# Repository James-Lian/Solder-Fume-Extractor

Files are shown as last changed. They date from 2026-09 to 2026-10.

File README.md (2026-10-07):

# 💨 Solder-Fume-Extractor
A small solder fume extractor complete with an air quality sensor for hobbyist soldering applications. Soldering can get pretty fume-y (pun intended), irritating the eyes, nose, and throat. While this extractor won't be as good as a commercial-grade fume hood, the filter will at least mitigate some of solder smoke. 
<br>
<br>
Encompasses a control board with the air quality sensor, a 12V PC fan, activated carbon filter, and custom-designed 3d-printed casing to house everything. 
<br>
<br>
Stardance Project Tracker (Devlogs): [https://stardance.hackclub.com/projects/36238](https://stardance.hackclub.com/projects/36238)



## 💡 Features
- powered by a [12V DC power supply](https://www.amazon.ca/dp/B09W8S3FBV)
- 0.91inch OLED SSD1306
- LM2596-3.3 buck converter for 3V3 supply
- ENS160+AHT21 sensor to detect VOCs and eCO2
- ESP-01S microcontroller
- custom 3d-printed casing
- [12V desk fan](https://www.amazon.ca/dp/B0DPWWMNYM) which pulls solder fumes through an [activated carbon filter](https://www.amazon.ca/dp/B0DVX29MLH?ref=ppx_yo2ov_dt_b_fed_asin_title)
- flip flop switch circuit + MOSFET to control the fan, flyback diode to prevent MOSFET damage

## 📄 PCB & Schematic


<br>
<br>
Note: additional space is intentionally left empty at the bottom left of the PCB to leave space for the sensor components.

## 🧱 CAD Model
The casing for both the controller board and desk fan were designed in Fusion360. The casing for the controller board covers all the components apart from the air quality sensor, which, of course, needs ample exposure to the air to make an accurate reading. 

## ⚙️ Assembly
1. Download the production files from the production folder and upload them to a manufacturer like JLCPCB
2. Upload the code to the ESP-01S through something like the [CP2102 module](https://www.amazon.ca/dp/B07D6LLX19)
3. After acquiring the PCB, solder all the components to the board. Ensure you leave enough spacing between the PCB and the [right-angle male headers](https://www.amazon.ca/dp/B01461DQ6S?ref=ppx_yo2ov_dt_b_fed_asin_title) for the fan's female connectors to fit.
4. The fan's casing is in three parts. Add heatset inserts to the thickest part, and then sandwich your activated carbon filter between the two grill frames before assembling all three together with 4 M3 screws.
5. The PCB's controller casing comes with an optional screw hole for secure placement. In my experience, it's not needed.  

## ⌨️ Code + Sensors
The code comes with preventative measures to prevent OLED screen burn in, such as by inverting or scrolling the text, and turning off the screen at times. Do note that the ENS160+AHT21 sensor needs to be (unfortunately) powered on for at least 24 hours (ideally 48) to output accurate readings. 

## 📋 BOM
Here's a list of components for the build (more complete version with links + prices in root repository):
### PCB
| Designator | Footprint | Quantity |
| --- | --- | --- |
| C1 680µF | CP_Radial_D10.0mm_P5.00mm | 1 |
| C2 220µF | CP_Radial_D6.3mm_P2.50mm | 1 |
| C3, C4 0.1µF | 0805 | 2 |
| C5 10nF | 0805 | 1 |
| C6 1µF | 0805 | 1 |
| D1 1N5822 | D_DO-201AD_P15.24mm_Horizontal | 1 |
| D2 1N4001 | D_DO-41_SOD81_P10.16mm_Horizontal | 1 |
| D3, D4 1N4148 | D_DO-35_SOD27_P7.62mm_Horizontal | 2 |
| J1 Barrel_Jack_Switch | XKB_DC-005-5A-2.0 | 1 |
| J2 [Fan](https://www.amazon.ca/dp/B0DPWWMNYM) | [PinHeader_1x03_P2.54mm_Horizontal](https://www.amazon.ca/dp/B01461DQ6S?ref=ppx_yo2ov_dt_b_fed_asin_title) | 1 |
| [Activated Carbon Filter](https://www.amazon.ca/dp/B0DVX29MLH?ref=ppx_yo2ov_dt_b_fed_asin_title) | | 1 |
| [12V DC Power Supply](https://www.amazon.ca/dp/B09W8S3FBV) | | 1 |
| L1 33µH | L_Bourns_SRU5016_5.2x5.2mm | 1 |
| Q1 STP55NF06L | TO-220-3_Vertical | 1 |
| Q2, Q3 PN2222 | TO-92_Inline | 2 |
| R1, R4, R5, R8 10kΩ | R_Axial_DIN0207_L6.3mm_D2.5mm_P7.62mm_Horizontal | 4 |
| R2, R3 1kΩ | R_Axial_DIN0207_L6.3mm_D2.5mm_P7.62mm_Horizontal | 2 |
| R6, R7 100kΩ | R_Axial_DIN0207_L6.3mm_D2.5mm_P7.62mm_Horizontal | 2 |
| SW1 CherryMXSwitch | SW_Cherry_MX_1.00u_PCB | 1 |
| U1 LM2596S-3.3 | TO-263-5_TabPin3 | 1 |
| U2 ESP-01S | PinSocket_2x04_P2.54mm_Vertical | 1 |
| U3 ENS160+AHT21 | PinSocket_1x08_P2.54mm_Vertical | 1 |
| U4 0.91inch SSD1306 OLED | ER_OLEDM0.91_1x-I2C | 1 |

## 🖼️ Final Build Pictures




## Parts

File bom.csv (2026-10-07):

Designator | Footprint | Quantity | Value | Link | Price (USD)
C1 | CP_Radial_D10.0mm_P5.00mm | 1 | 680µF | https://www.lcsc.com/product-detail/C23777.html?s_z=n_q_GR687M035G20RR0VL4FP0 | $0.48
C2 | CP_Radial_D6.3mm_P2.50mm | 1 | 220µF | https://www.lcsc.com/product-detail/C2036.html?s_z=n_q_C2036&globalKeyword=C2036 | $0.08
C3, C4 | 0805 | 2 | 0.1µF | https://www.lcsc.com/product-detail/C1711.html?s_z=n_q_C1711&globalKeyword=C1711 | $0.32
C5 | 0805 | 1 | 10nF | https://www.lcsc.com/product-detail/C1710.html?s_z=n_q_CL21B103KBANNNC | $0.0116
C6 | 0805 | 1 | 1µF | https://www.lcsc.com/product-detail/C2907219.html?s_z=n_q_p_1%2520%25C2%25B5F%25200805 | $0.34
D1 | D_DO-201AD_P15.24mm_Horizontal | 1 | 1N5822 | https://www.lcsc.com/product-detail/C2476.html?s_z=n_q_C2476&globalKeyword=C2476 | $0.35
D2 | D_DO-41_SOD81_P10.16mm_Horizontal | 1 | 1N4001 | https://www.lcsc.com/product-detail/C47018536.html?s_z=n_q_C47018536&globalKeyword=C47018536 | $0.08
D3, D4 | D_DO-35_SOD27_P7.62mm_Horizontal | 2 | 1N4148 | https://www.lcsc.com/product-detail/C85057.html?s_z=n_q_C85057&globalKeyword=C85057 | $0.11
J1 | XKB_DC-005-5A-2.0 | 1 | Barrel_Jack_Switch | https://www.lcsc.com/product-detail/C381116.html?s_z=n_q_C381116&globalKeyword=C381116 | $0.52
J2 | PinHeader_1x03_P2.54mm_Horizontal | 1 | Fan | https://www.amazon.ca/dp/B01461DQ6S?ref=ppx_yo2ov_dt_b_fed_asin_title | $2.19
12V Desk Fan | N/A | 1 | N/A | https://www.amazon.ca/dp/B0DPWWMNYM | $12.00
Activated Carbon Filter | N/A | 1 | N/A | https://amazon.ca/dp/B0DVX29MLH?ref=ppx_yo2ov_dt_b_fed_asin_title | $14.05
12V DC Power Supply | N/A | 1 | N/A | https://www.amazon.ca/dp/B09W8S3FBV?th=1 | $10.20
L1 | L_Bourns_SRU5016_5.2x5.2mm | 1 | 33µH | https://www.lcsc.com/product-detail/C5760316.html?s_z=n_q_C5760316&globalKeyword=C5760316 | $1.29
Q1 | TO-220-3_Vertical | 1 | STP55NF06L | https://www.lcsc.com/product-detail/C77582.html?s_z=n_q_C77582&globalKeyword=C77582 | $2.57
Q2, Q3 | TO-92_Inline | 2 | PN2222 | https://www.lcsc.com/product-detail/C50229644.html?s_z=n_q_2n2222%2520TO-92 | $0.05
R1, R4, R5, R8 | R_Axial_DIN0207_L6.3mm_D2.5mm_P7.62mm_Horizontal | 4 | 10kΩ | https://www.amazon.ca/dp/B07L851T3V?ref=ppx_yo2ov_dt_b_fed_asin_title&th=1 | $0.03
R2, R3 | R_Axial_DIN0207_L6.3mm_D2.5mm_P7.62mm_Horizontal | 2 | 1kΩ | https://www.amazon.ca/dp/B07L851T3V?ref=ppx_yo2ov_dt_b_fed_asin_title&th=1 | $0.01
R6, R7 | R_Axial_DIN0207_L6.3mm_D2.5mm_P7.62mm_Horizontal | 2 | 100kΩ | https://www.amazon.ca/dp/B07L851T3V?ref=ppx_yo2ov_dt_b_fed_asin_title&th=1 | $0.01
SW1 | SW_Cherry_MX_1.00u_PCB | 1 | SW_Push | https://www.amazon.ca/dp/B0GY8BWBYJ?ref=ppx_yo2ov_dt_b_fed_asin_title | $0.18
U1 | TO-263-5_TabPin3 | 1 | LM2596S-3.3 | https://www.lcsc.com/product-detail/C42421958.html?s_z=n_q_C42421958&globalKeyword=C42421958 | $1.21
U2 | PinSocket_2x04_P2.54mm_Vertical | 1 | ESP-01S | https://www.amazon.ca/dp/B00O34AGSU | $7.04
U3 | PinSocket_1x08_P2.54mm_Vertical | 1 | ENS160+AHT21 | https://www.amazon.ca/dp/B0DH4M3JYW | $12.66
U4 | ER_OLEDM0.91_1x-I2C | 1 | ER_OLEDM0.91_1x-I2C | https://www.amazon.ca/dp/B085NHJYBV?th=1 (3 units) | $3.75

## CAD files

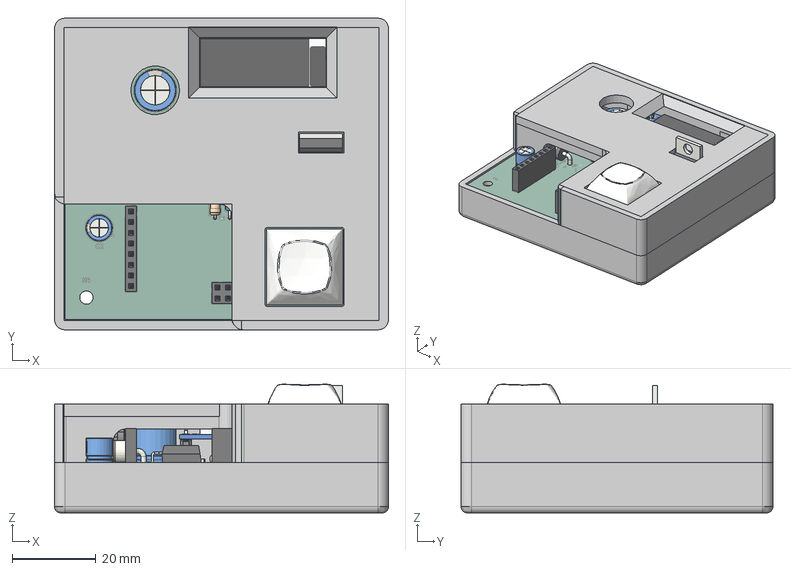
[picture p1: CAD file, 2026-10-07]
cad/DIY_Solder_Fume_PCB.step
79.6 x 74.3 x 30.7 mm
MX Mount v1

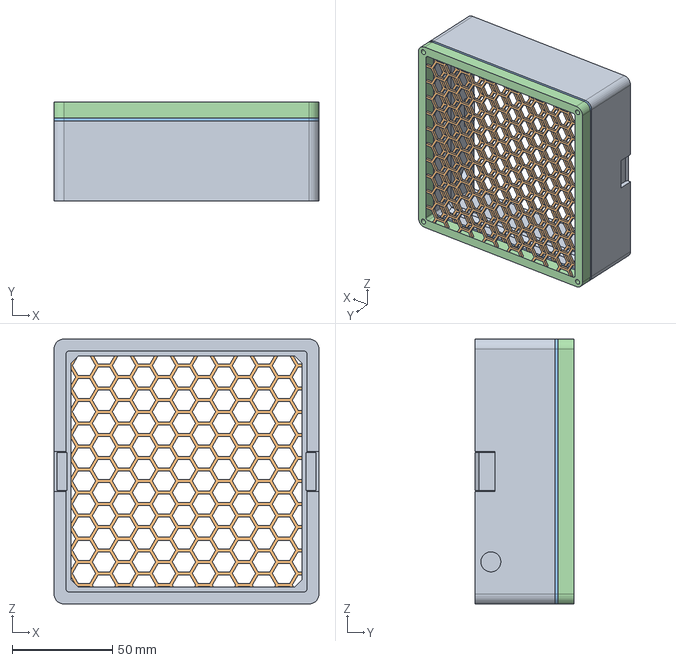
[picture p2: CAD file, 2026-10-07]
cad/DIY_Solder_Fume_Fan_Holder.step
132.0 x 49.5 x 132.0 mm

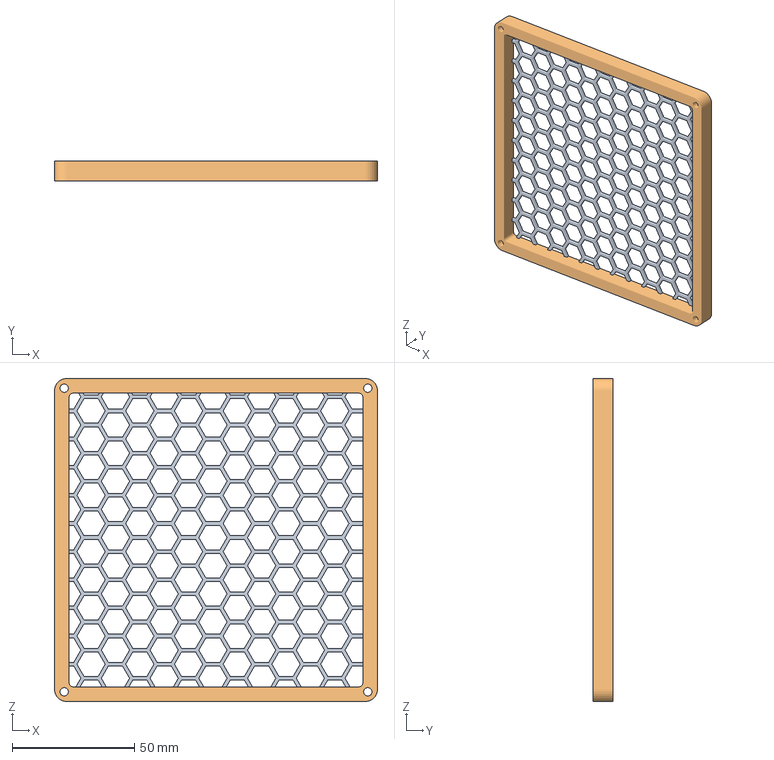
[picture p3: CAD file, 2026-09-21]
cad/FanGrill2.3mf
132.0 x 8.00 x 132.0 mm
Grill2
Grill2F

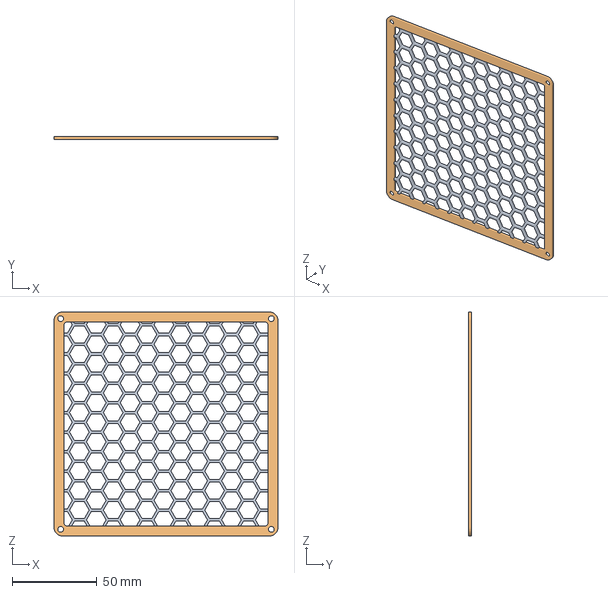
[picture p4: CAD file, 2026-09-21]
cad/FanGrill1.3mf
132.0 x 1.50 x 132.0 mm
Grill1
Grill1F

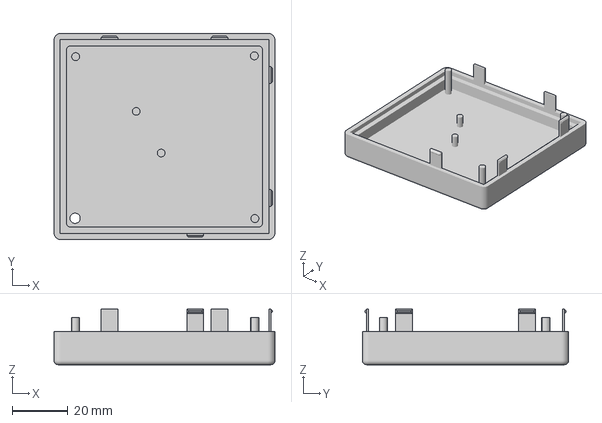
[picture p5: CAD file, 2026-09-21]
cad/Case_Bottom.3mf
79.6 x 74.3 x 20.0 mm

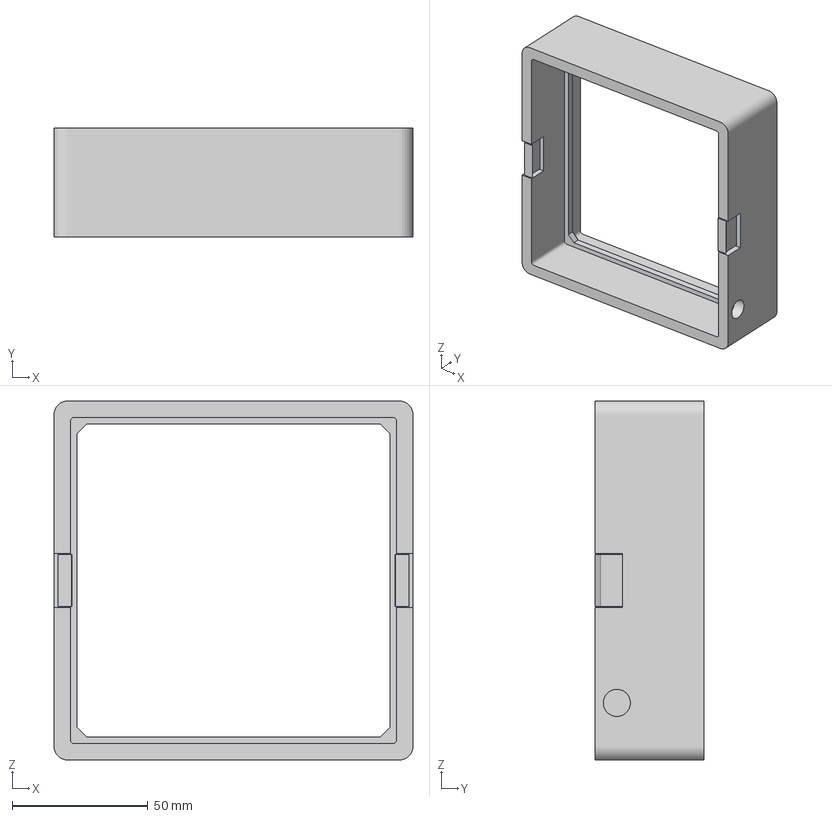
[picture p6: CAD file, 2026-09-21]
cad/FanBody.3mf
132.0 x 40.0 x 132.0 mm

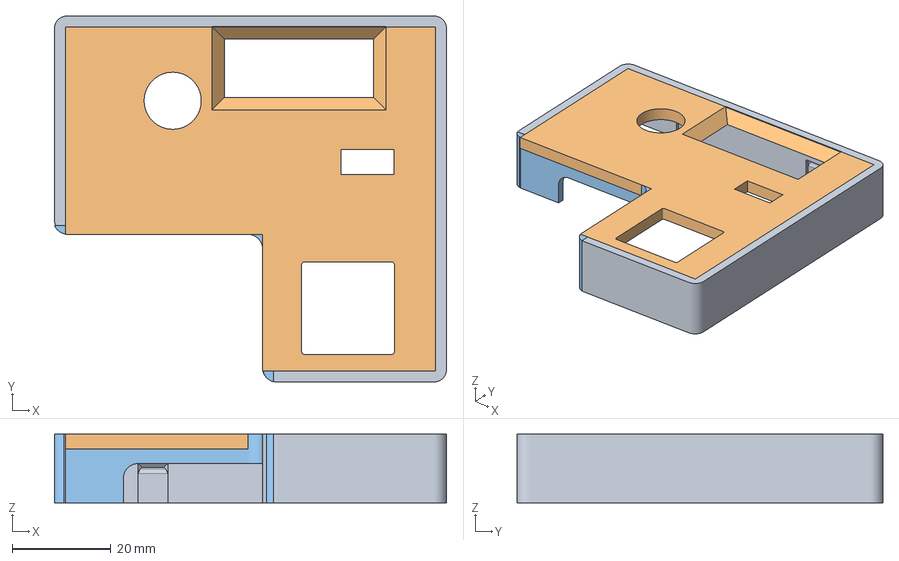
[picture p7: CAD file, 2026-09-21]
cad/Case_Top.3mf
79.6 x 74.3 x 14.0 mm

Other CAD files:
cad/DIY_Solder_Fume_Fan_Holder.f3d
cad/DIY_Solder_Fume_PCB.f3d

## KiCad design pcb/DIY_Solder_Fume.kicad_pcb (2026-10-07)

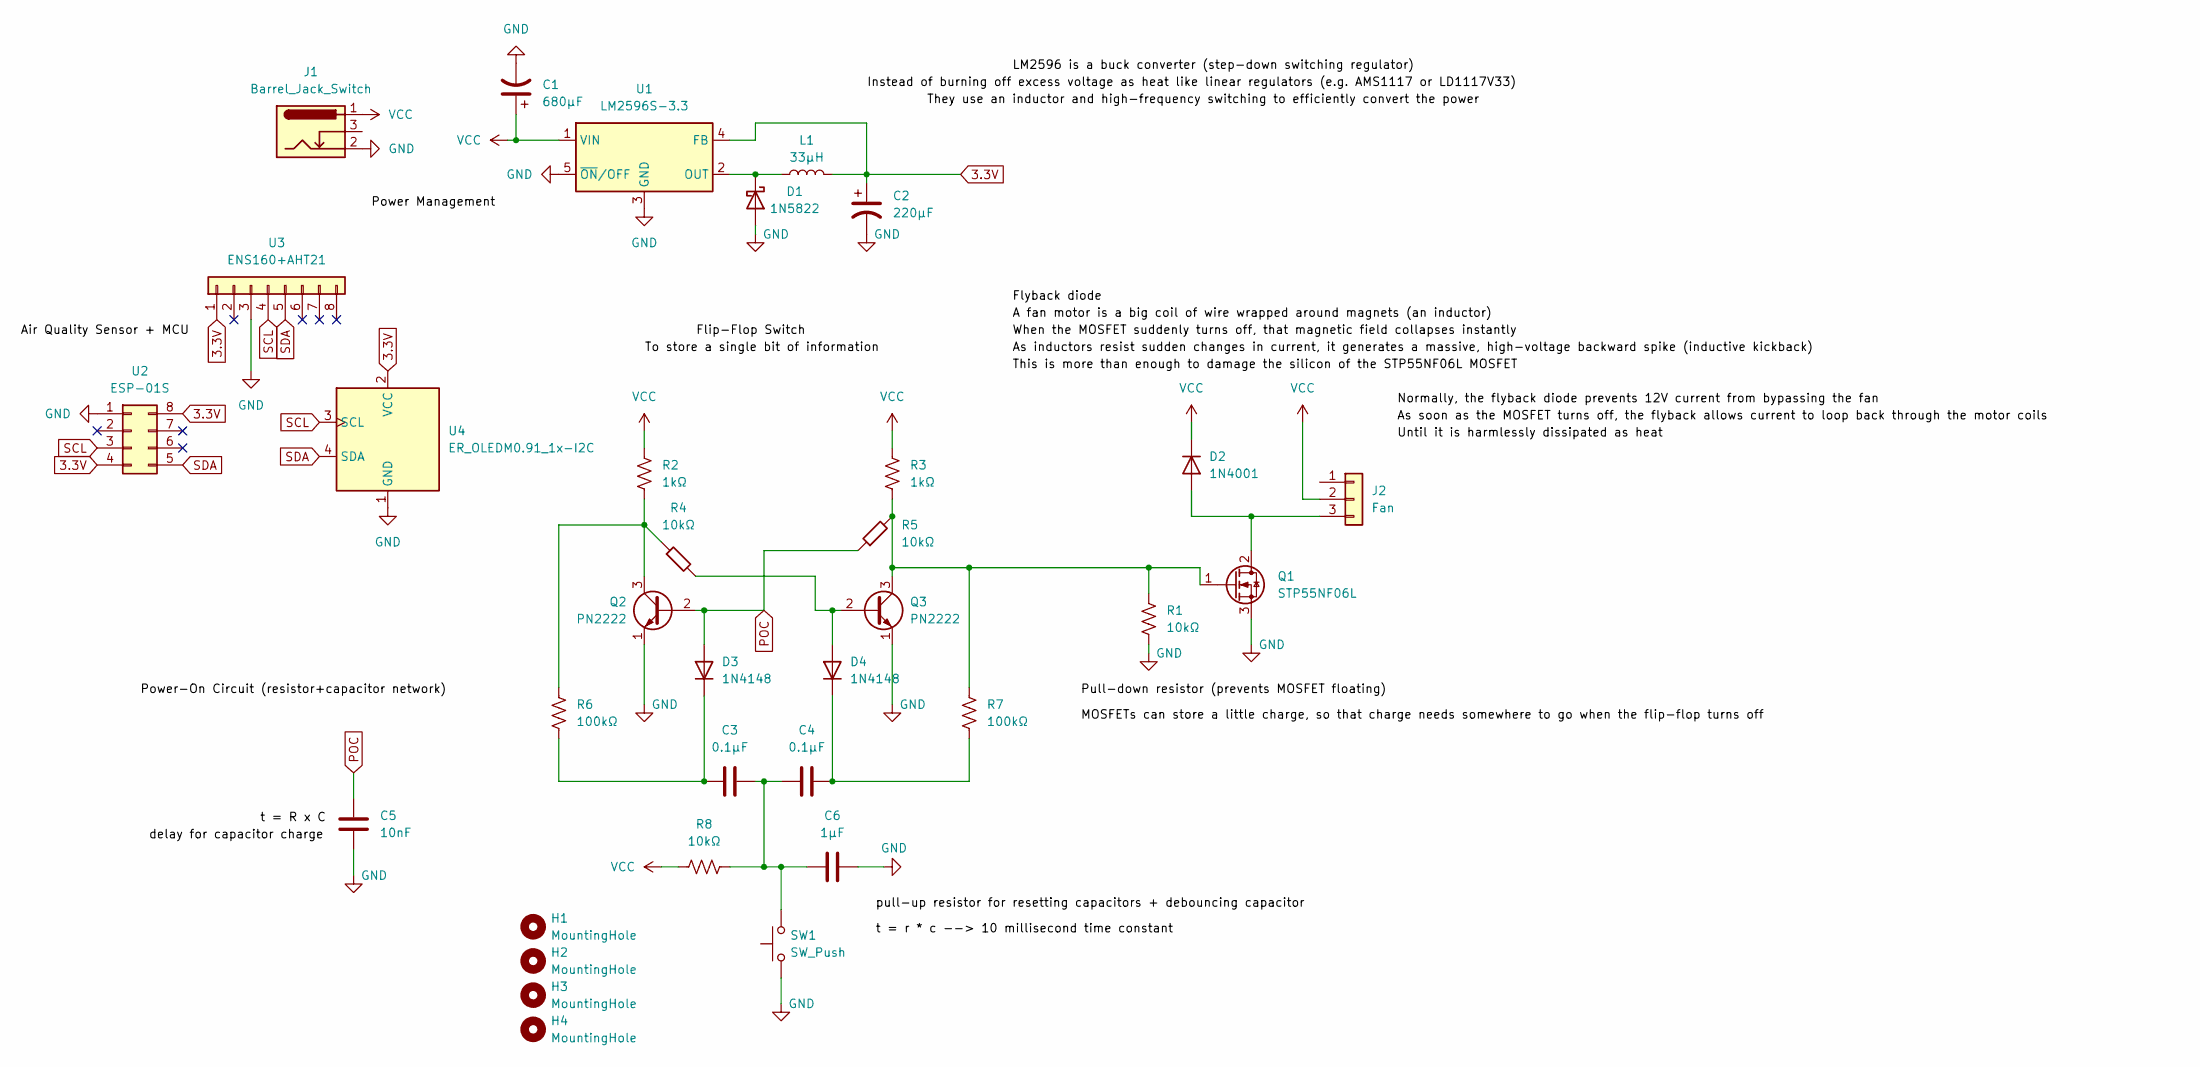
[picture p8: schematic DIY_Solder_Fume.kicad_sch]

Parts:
C1: 680µF; CP_Radial_D10.0mm_P5.00mm
C2: 220µF; CP_Radial_D6.3mm_P2.50mm
C3, C4: 0.1µF; C_0805_2012Metric
C5: 10nF; C_0805_2012Metric
C6: 1µF; C_0805_2012Metric
D1: 1N5822; D_DO-201AD_P15.24mm_Horizontal
D2: 1N4001; D_DO-41_SOD81_P10.16mm_Horizontal
D3, D4: 1N4148; D_DO-35_SOD27_P7.62mm_Horizontal
H1, H2, H3, H4: MountingHole; MountingHole_3.2mm_M3_Pad
J1: Barrel_Jack_Switch; XKB_DC-005-5A-2.0
J2: Fan; PinHeader_1x03_P2.54mm_Horizontal
L1: 33µH; L_Bourns_SRU5016_5.2x5.2mm
Q1: STP55NF06L; TO-220-3_Vertical
Q2, Q3: PN2222; TO-92_Inline
R1, R4, R5, R8: 10kΩ; R_Axial_DIN0207_L6.3mm_D2.5mm_P7.62mm_Horizontal
R2, R3: 1kΩ; R_Axial_DIN0207_L6.3mm_D2.5mm_P7.62mm_Horizontal
R6, R7: 100kΩ; R_Axial_DIN0207_L6.3mm_D2.5mm_P7.62mm_Horizontal
SW1: SW_Push; SW_Cherry_MX_1.00u_PCB
U1: LM2596S-3.3; TO-263-5_TabPin3
U2: ESP-01S; PinSocket_2x04_P2.54mm_Vertical
U3: ENS160+AHT21; PinSocket_1x08_P2.54mm_Vertical
U4: ER_OLEDM0.91_1x-I2C

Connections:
3.3V: C2.1, L1.2, U1.4 (FB), U2.4, U2.8, U3.1, U4.2 (VCC)
GND: C1.2, C2.2, C5.1, C6.1, D1.2 (A), J1.2, Q1.3 (S), Q2.1 (E), Q3.1 (E), R1.2, SW1.1, U1.3 (GND), U1.5 (~ON/OFF), U2.1, U3.3, U4.1 (GND)
unnamed: C3.2, C4.2, C6.2, R8.2, SW1.2
unnamed: D1.1 (K), L1.1, U1.2 (OUT)
unnamed: D2.2 (A), J2.3, Q1.2 (D)
unnamed: C3.1, D3.1 (K), R6.2
unnamed: D4.2 (A), Q3.2 (B), R4.2
unnamed: C4.1, D4.1 (K), R7.2
unnamed: Q1.1 (G), Q3.3 (C), R1.1, R3.2, R5.2, R7.1
unnamed: Q2.3 (C), R2.2, R4.1, R6.1
POC: C5.2, D3.2 (A), Q2.2 (B), R5.1
SCL: U2.3, U3.4, U4.3 (SCL)
SDA: U2.5, U3.5, U4.4 (SDA)
VCC: C1.1, D2.1 (K), J1.1, J2.2, R2.1, R3.1, R8.1, U1.1 (VIN)

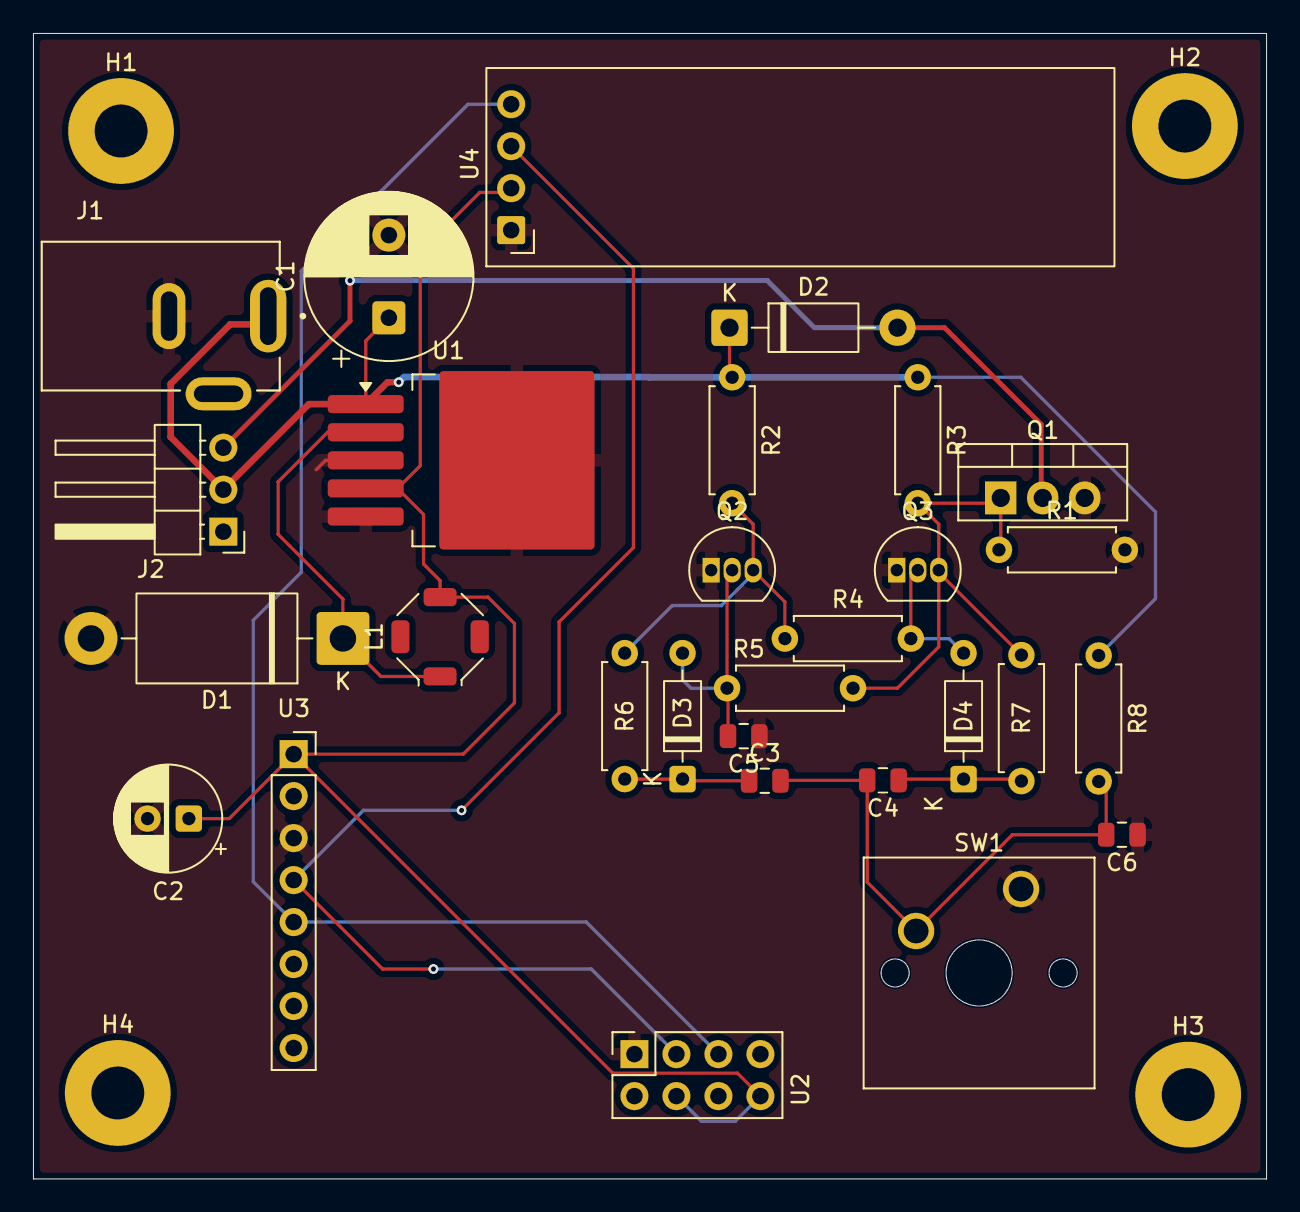
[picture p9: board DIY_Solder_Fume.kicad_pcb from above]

Board: 2 copper layers, 74.6 x 69.3 mm, 33 parts (0 on the bottom side), 14 nets.

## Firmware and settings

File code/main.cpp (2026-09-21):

#include <Arduino.h>
#include <Wire.h> // enables I2C communication
#include <Adafruit_GFX.h>
#include <Adafruit_SSD1306.h>
#include <Adafruit_AHTX0.h> // AHT21 library

#include "ScioSense_ENS160.h"  // ENS160 library

#define SCREEN_WIDTH 128 // OLED display width, in pixels
#define SCREEN_HEIGHT 32 // OLED display height, in pixels

#define SCREEN_ADDRESS 0x3C
Adafruit_SSD1306 display(SCREEN_WIDTH, SCREEN_HEIGHT, &Wire);

// AHT21 = temperature and humidity sensor
#define AHT21_ADDRESS 0x38
Adafruit_AHTX0 aht; 
#define separatorStr "--------------------------------------------------"
// AHT21 variables
float tempC; 
float tempF; 
float humidity;

// ENS160 = digital gas sensor
#define ENS160_ADDRESS 0x53
ScioSense_ENS160 ens160(ENS160_ADDRESS);
// ENS160 variables
int aqi = 0; // air quality index (1 to 5)
int tvoc = 0; // total VOCs (Volatile Organic Compounds) concentation in ppb (0 - 65000 ppb)
int eco2 = 0; // estimated CO2 equivalent (400 to 65000 ppm)

void setup() {
    Serial.begin(115200);
    while (!Serial);
    Serial.println("\nI2C Air Quality Sensor + OLED Display");

	Serial.println("Initializing I2C SSD1306 OLED...");
    // SDA = GPIO0, SCL = GPIO2
    Wire.begin(0, 2);
	Serial.println("SSD1306 initialized.");
	Serial.println(separatorStr);
	Serial.println();

	Serial.println("ENS160...");
	ens160.begin();
	delay(100);
	Serial.println(ens160.available() ? "ENS160 initialized." : "ENS160 initialization failed.");
	if (ens160.available()) {
		ens160.setMode(ENS160_OPMODE_STD); // begin() leaves the chip in IDLE; switch to Standard mode so it senses
	}
	Serial.println(separatorStr);

	if(!display.begin(SSD1306_SWITCHCAPVCC, SCREEN_ADDRESS)) {
		Serial.println(F("SSD1306 allocation failed"));
		for(;;); // Don't proceed, loop forever
	}

	bool okAht = aht.begin();
	if (!okAht) {
		Serial.println("AHT21 initialization failed.");
	}

	display.dim(true);
	display.setTextWrap(false); // clip at the panel edge instead of wrapping overflow onto a new line

	// clear buffer and show initial graphics
	display.clearDisplay();
	display.setTextSize(1);
	display.setTextColor(WHITE);
	display.setCursor(0, 0);
	display.println(F("Starting AQI sensor...")); // keeps strings in flash instead of dynamic RAM
	display.display();

	// scroll entire display to the right
	display.startscrollleft(0x00, 0x0F);
	delay(1500);
	display.stopscroll();
	display.setTextSize(1);
}

void loop() {
	uint32_t now = millis();
	static uint32_t lastSensor = 0;
	static uint32_t lastScroll = 0;
	static int scrollOffset = 0;

	// --- Sample sensors once per second ---
	if (now - lastSensor >= 1000) {
		lastSensor = now;

		sensors_event_t humidity1, temp;
		aht.getEvent(&humidity1, &temp);
		tempC = temp.temperature;
		tempF = temp.temperature * 9.0f / 5.0f + 32.0f;
		humidity = humidity1.relative_humidity;

		Serial.print("Temperature: ");
		Serial.print(tempC);
		Serial.print(" degrees C; ");
		Serial.print(tempF);
		Serial.println(" degrees F");

		Serial.print("Humidity: ");
		Serial.print(humidity);
		Serial.println("% rH");

		if (ens160.available()) {
			// Non-blocking: read whatever the ENS160 produced in its 1s cycle.
			// (measure(true) would block ~1s each call and stall the scroll.)
			ens160.set_envdata(tempC, humidity);
			ens160.measure(false);
			ens160.measureRaw(false);

			aqi  = ens160.getAQI();
			tvoc = ens160.getTVOC();
			eco2 = ens160.geteCO2();

			Serial.print("AQI: ");
			Serial.println(aqi);
			Serial.print("TVOC: ");
			Serial.print(tvoc);
			Serial.println("ppb");
			Serial.print("eCO2: ");
			Serial.print(eco2);
			Serial.println("ppm");
		}
	}

	// --- Build the two lines of text ---
	// NOTE: ESP8266 printf doesn't support %f, so format the floats first with dtostrf and stitch them into the line with integer %s
	char tmp1[8], tmp2[8], tmp3[8];
	dtostrf(tempC, 4, 1, tmp1);
	dtostrf(tempF, 6, 1, tmp2);
	dtostrf(humidity, 5, 1, tmp3);

	char line1[40];
	char line2[64];
	snprintf_P(line1, sizeof(line1), PSTR("%s C  %s F  %s %%rH"),
	           tmp1, tmp2, tmp3);
	if (ens160.available()) {
		snprintf_P(line2, sizeof(line2),
		           PSTR("AQI:%d | TVOC:%d ppb | eCO2:%d ppm"), aqi, tvoc, eco2);
	} else {
		snprintf_P(line2, sizeof(line2), PSTR("ENS160 not available"));
	}

	// Measure the wider line once and keep that scroll distance fixed so the
	// marquee doesn't jerk around when the digit widths change.
	static uint16_t scrollLimit = 0;
	if (scrollLimit == 0) {
		int16_t x1, y1, x2, y2;
		uint16_t w1 = 0, h1 = 0, w2 = 0, h2 = 0;
		display.getTextBounds(line1, 0, 0, &x1, &y1, &w1, &h1);
		display.getTextBounds(line2, 0, 0, &x2, &y2, &w2, &h2);
		// drawX starts at 128 (off the right edge) and must reach -maxW
		// (off the left edge), so the total travel is SCREEN_WIDTH + maxW,
		// plus a trailing gap for a blank pause before the loop restarts.
		const uint8_t scrollGap = 40;
		scrollLimit = SCREEN_WIDTH + (uint16_t)(w1 > w2 ? w1 : w2) + scrollGap;
	}

	//-----------------------------------------------------------------------------
	// Preventing OLED burn-in cycles
	// - phase 0: normal text
	// - phase 1: inverted text
	// - phase 2: all-black (fixed 7s)
	static uint32_t phaseStart = 0;
	static uint8_t phase = 0;

	// redraw further left every ~100 ms ---
	if (now - lastScroll >= 100) {
		lastScroll = now;
		if (phase == 2) {
			// Rest period
			display.invertDisplay(false);
			display.clearDisplay();
			display.display();
			// Phase 2 is 7s rest
			if (now - phaseStart >= 10000) {
				phase = 0;
				phaseStart = now;
			}
		} else {
			int16_t drawX = 128 - scrollOffset;

			display.clearDisplay();
			display.invertDisplay(phase == 1);
			display.setCursor(drawX, 4);
			display.print(line1);
			display.setCursor(drawX, 20);
			display.print(line2);
			display.display();

			// Advance one step toward the left edge.
			scrollOffset += 5;
			// When the text has finished a full pass across the panel,
			// move on to the next phase and restart the scroll.
			if (scrollOffset >= scrollLimit) {
				scrollOffset = 0;
				phase = (uint8_t)(phase + 1); // 0 -> 1 -> 2
				phaseStart = now;
			}
		}
	}
}

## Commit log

2026-09-16 Update from local repo
    [DIY_Solder_Fume.kicad_pcb, DIY_Solder_Fume.kicad_sch, bom.csv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]
2026-09-21 Enhance README with features and assembly details
    Expanded the README to include detailed features, assembly instructions, and final build pictures.
2026-09-21 Add I2C air quality sensor and OLED display code
2026-09-21 Add PlatformIO configuration for ESP01 1M board
2026-09-21 Update assembly instructions in README
    Added instructions for assembling the fan casing and PCB controller.
2026-09-29 Add root directory bom
    [bom.csv]
2026-09-29 Revise README for solder fume extractor clarity
    Updated the description to clarify the purpose and functionality of the solder fume extractor, emphasizing its benefits for hobbyist soldering applications.
2026-09-29 Add BOM section to README
    Added a Bill of Materials (BOM) section with component details.
2026-10-07 Modify bom.csv to add pricing and links
    Updated bill of materials to include links and prices for components.
    [bom.csv]
2026-10-07 Fix CSV formatting by adding a trailing comma
    [bom.csv]
2026-10-07 Update bom.csv with additional fields and entries
    [bom.csv]
2026-10-07 Fix BOM CSV formatting issues
    [bom.csv]
2026-10-07 Update bom.csv with new components and remove duplicates
    Removed duplicate entries and added new components with links and prices.
    [bom.csv]
2026-10-07 Update bom.csv
    Updated the URL for the Activated Carbon Filter to a more direct link.
    [bom.csv]
2026-10-07 Modify bom.csv for price column and formatting
    Updated the price column to 'Price per unit (USD)' and adjusted price formatting.
    [bom.csv]
2026-10-07 Revise BOM with pricing and links for components
    Updated component details with links and prices.
    [bom.csv]
2026-10-07 Enhance BOM section with additional details
    Updated BOM section to include a note about a more complete version with links and prices.
